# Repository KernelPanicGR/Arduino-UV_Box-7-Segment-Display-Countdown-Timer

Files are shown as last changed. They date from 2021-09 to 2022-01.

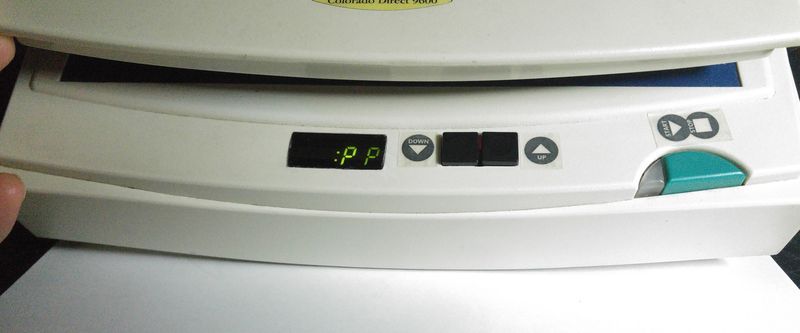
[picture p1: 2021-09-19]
Photos/Arduino_Countdown_Timer_7seg09.jpg

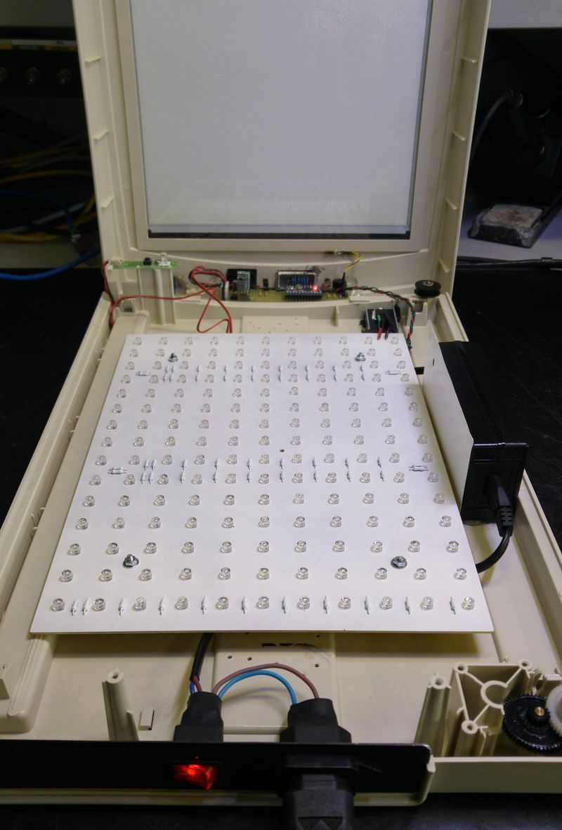
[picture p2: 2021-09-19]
Photos/Arduino_Countdown_Timer_7seg05.jpg

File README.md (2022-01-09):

# Arduino UV Box Countdown Timer 
Multiplexing 4-Digit 7-Segment Display<br/>
Easy change between Common Cathode or Common Anode Displays<br/>
Stores values into the EEPROM <br/>
max. countdown time 99:59 [min:sec]<br/>
Video https://vimeo.com/608781008<br/>

To change the countdown time, press the UP & DOWN buttons together.<br/>
With the UP or DOWN buttons put the time you want in minutes and press START/STOP which now works as SET. <br/>
Now change the seconds and press START/STOP again.<br/>
If other knowledge, repeat the previous steps, if you are ready press START/STOP to start the countdown.<br/>
If the time was different from the previous one Arduino had in EEPROM, the word Set will appear on the screen first,<br/>
the new time in EEPROM will be saved and then the reverse will start.

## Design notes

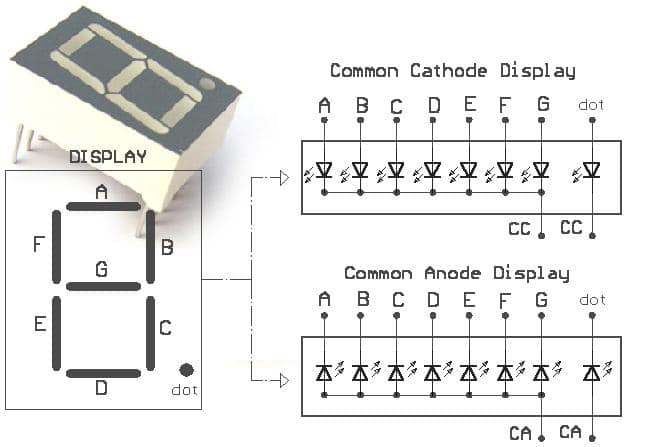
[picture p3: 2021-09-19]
Schematics/Diagram_7-Segment_Display.jpg

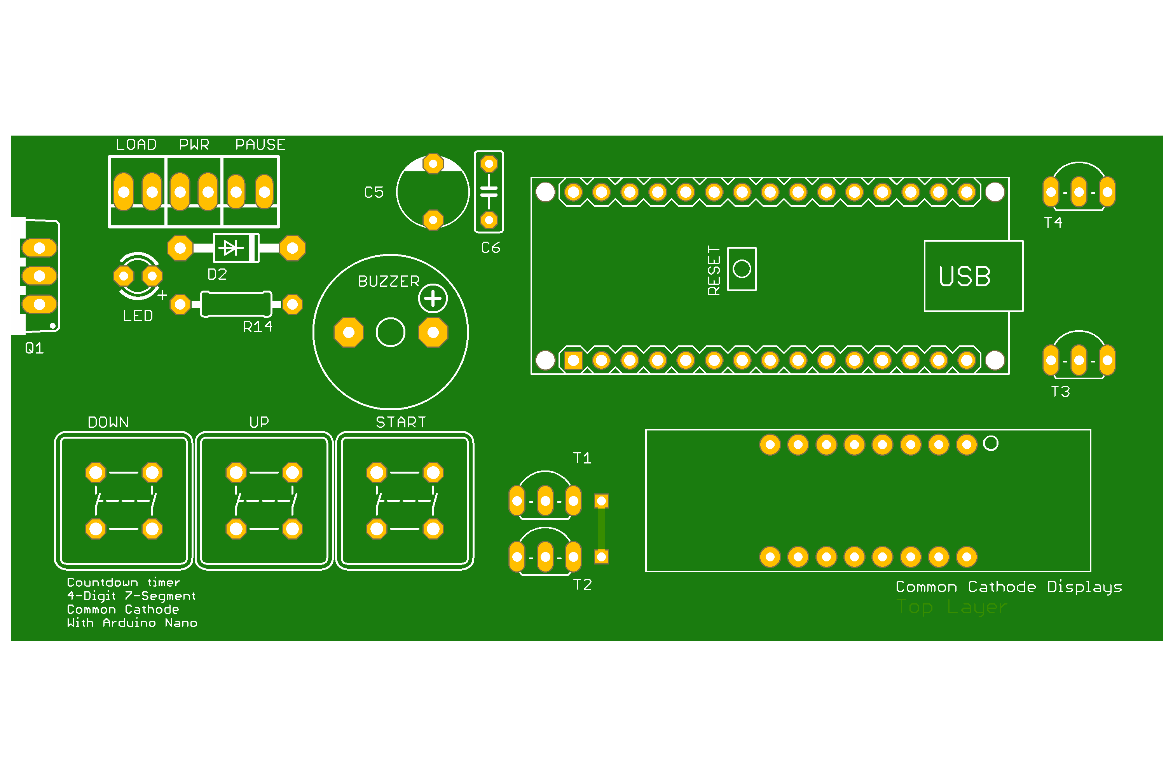
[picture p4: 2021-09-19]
Schematics/Arduino_Nano_Countdown_Timer_7-seg_CC_Top.png

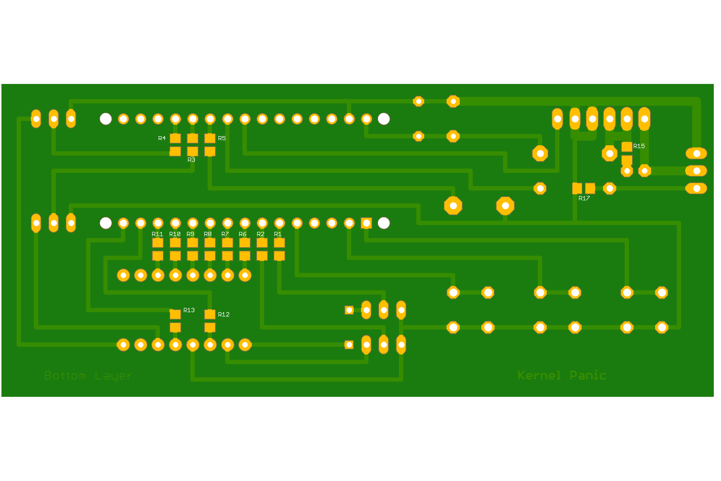
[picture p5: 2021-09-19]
Schematics/Arduino_Nano_Countdown_Timer_7-seg_CC_Bottom.png

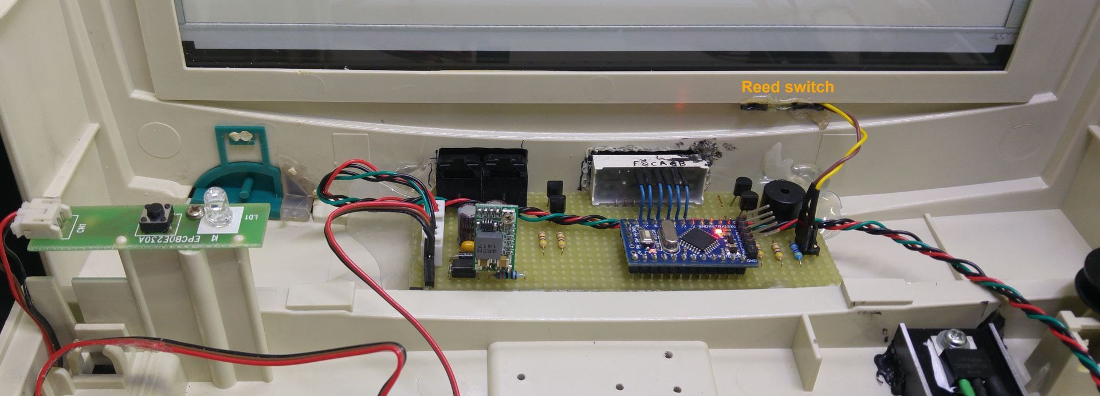
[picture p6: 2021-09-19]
Photos/Arduino_Countdown_Timer_7seg03.jpg

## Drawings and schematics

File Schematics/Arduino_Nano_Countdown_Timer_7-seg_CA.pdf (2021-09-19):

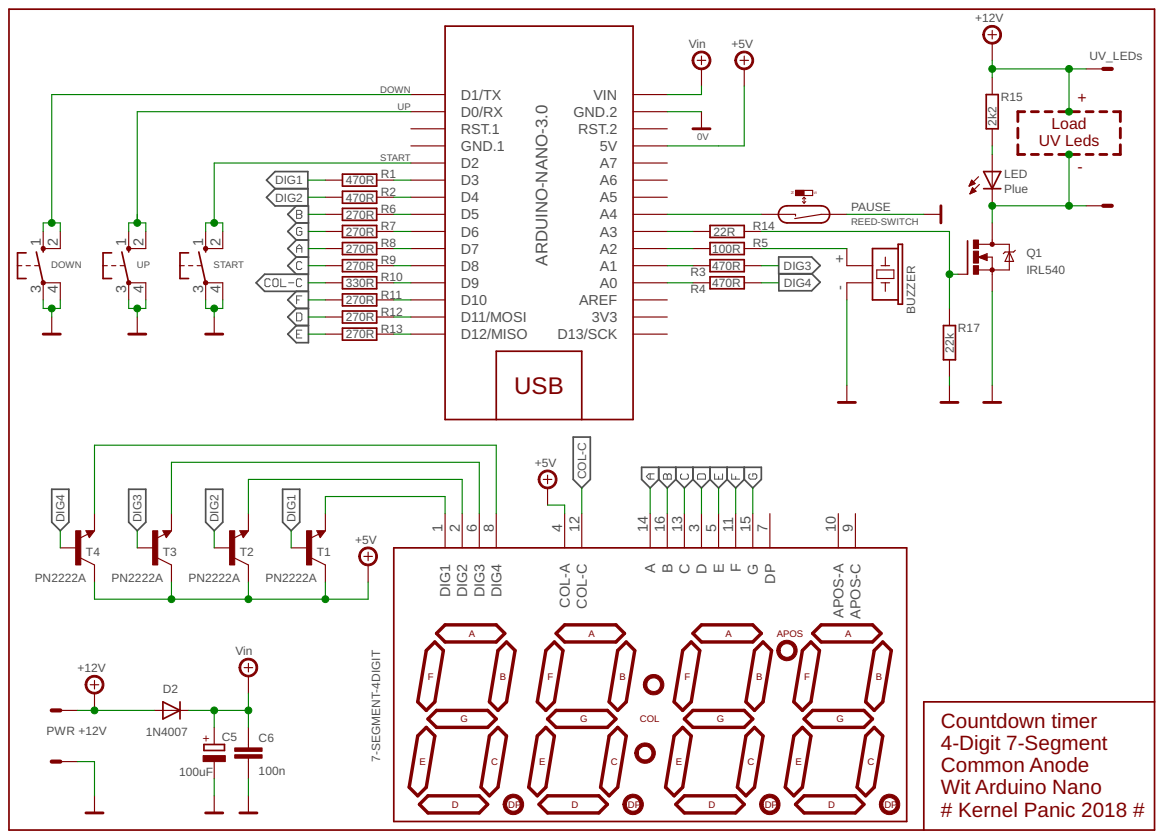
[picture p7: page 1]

DOWN
D1/TX D0/RX RST.1 GND.1 D2 D3 D4 D5 D6 D7 D8 D9 D10 D11/MOSI D12/MISO

270R | 470R
330R | 470R

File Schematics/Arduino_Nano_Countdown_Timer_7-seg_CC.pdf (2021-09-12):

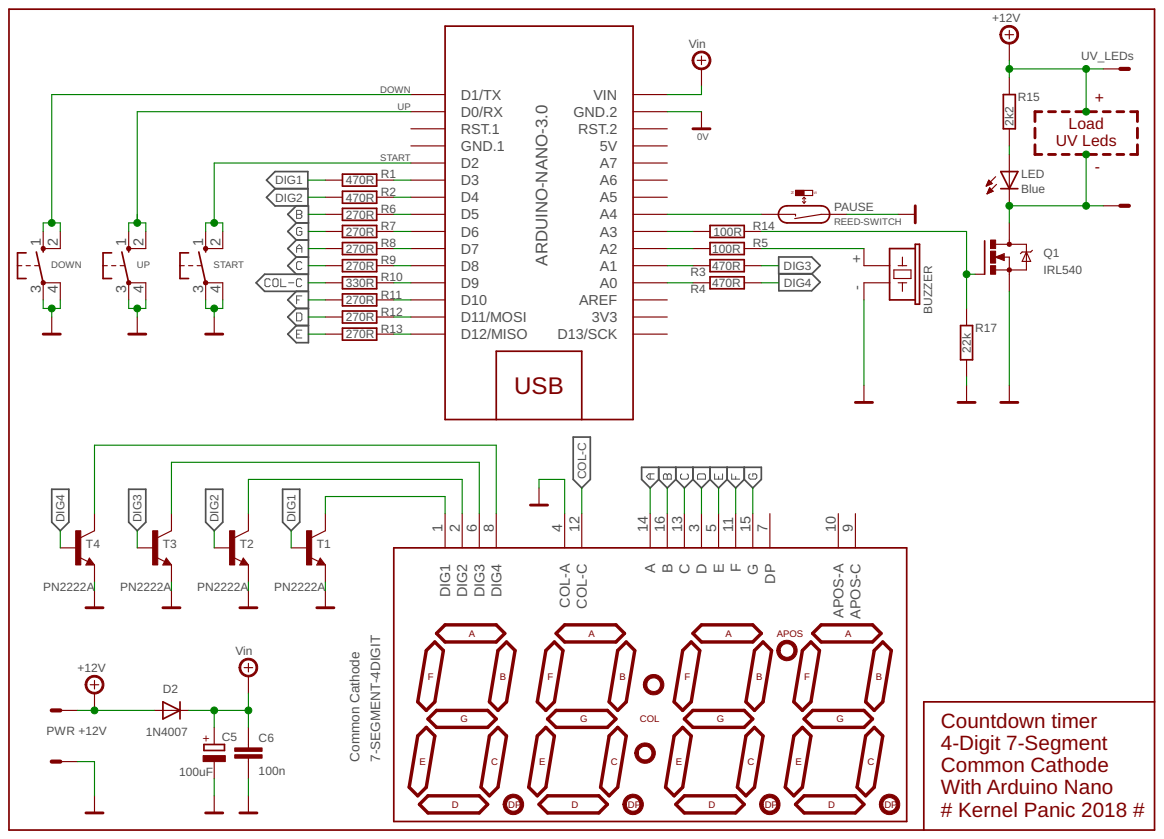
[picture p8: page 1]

DOWN
D1/TX D0/RX RST.1 GND.1 D2 D3 D4 D5 D6 D7 D8 D9 D10 D11/MOSI D12/MISO

270R | 470R
330R | 470R

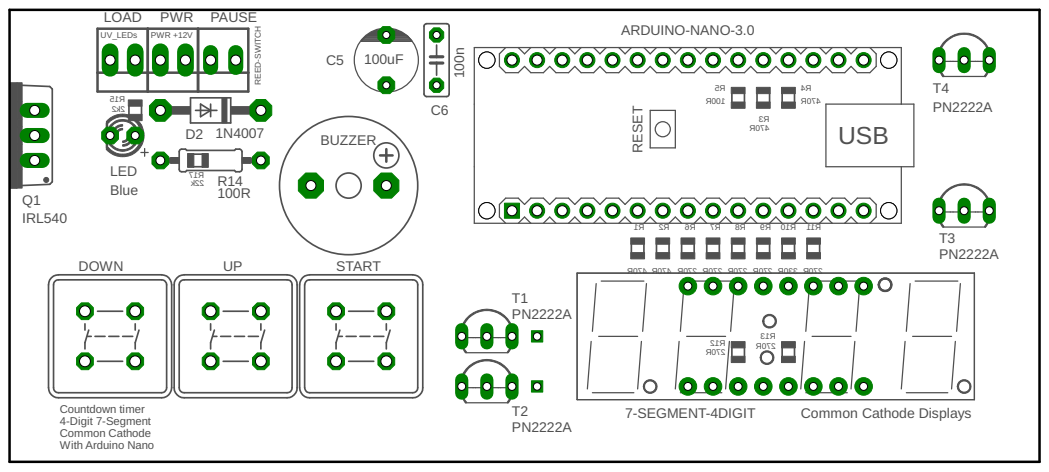
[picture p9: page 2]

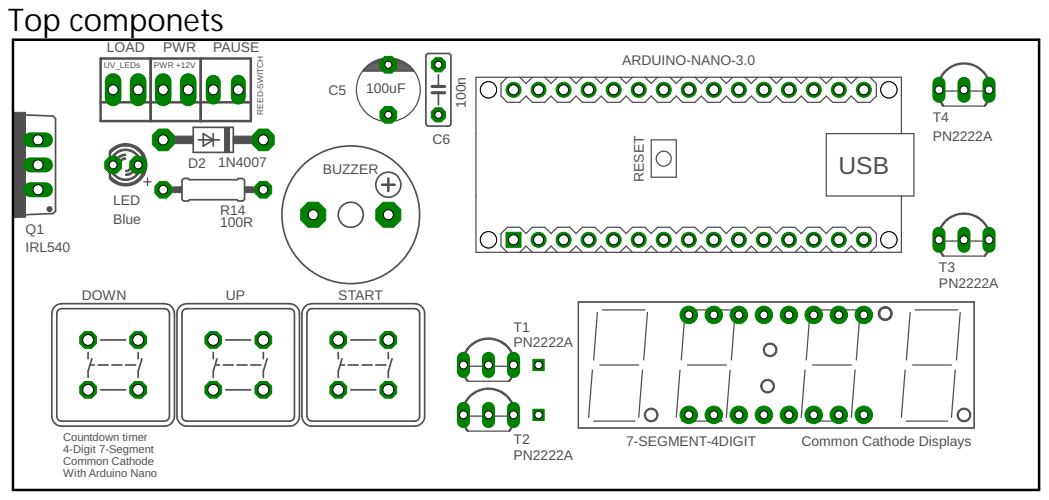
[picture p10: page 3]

Countdown timer 4-Digit 7-Segment Common Cathode With Arduino Nano

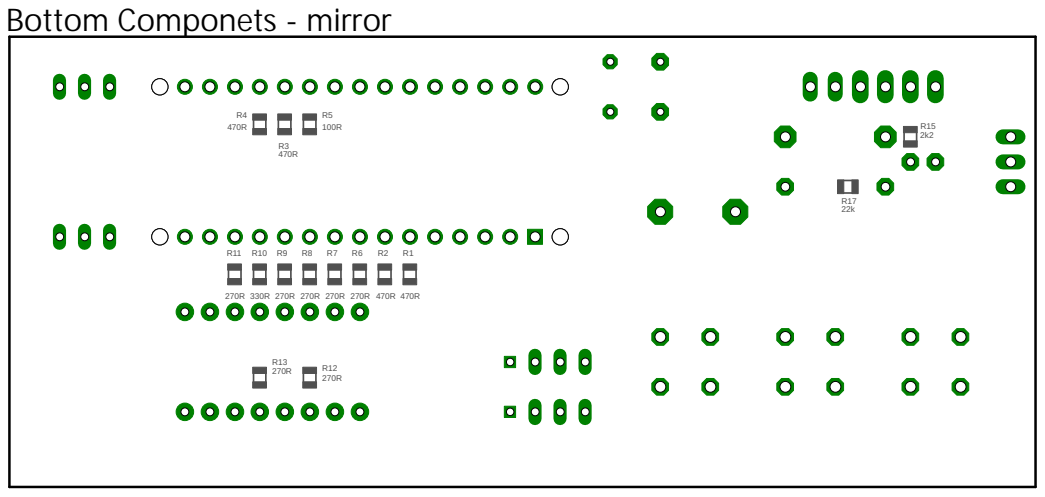
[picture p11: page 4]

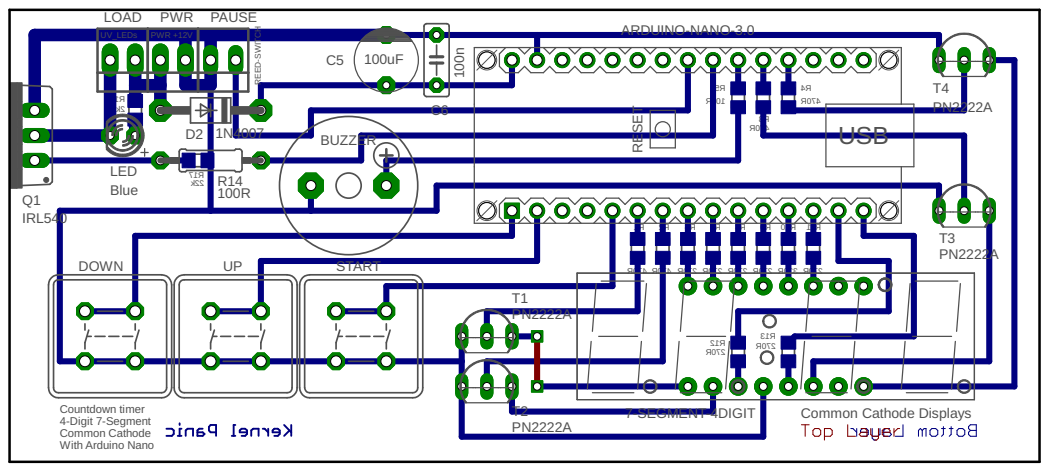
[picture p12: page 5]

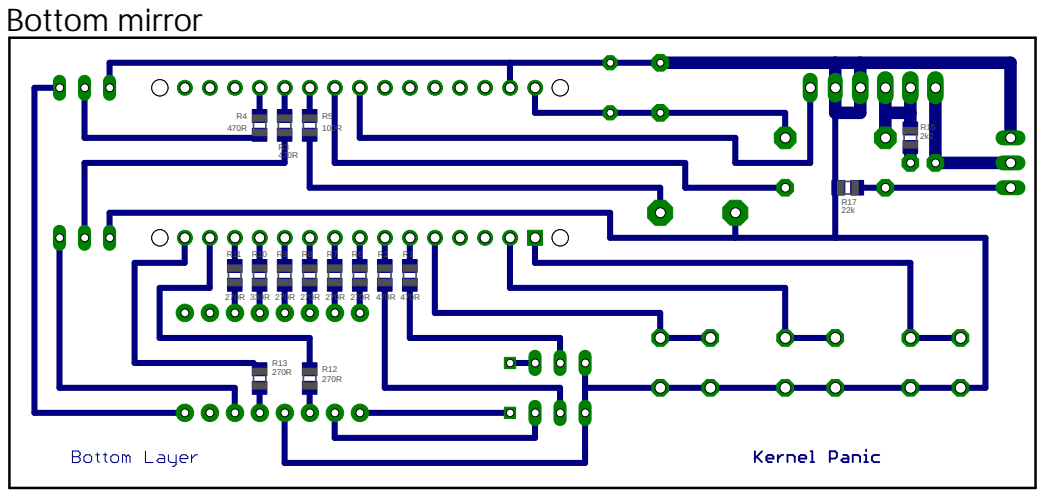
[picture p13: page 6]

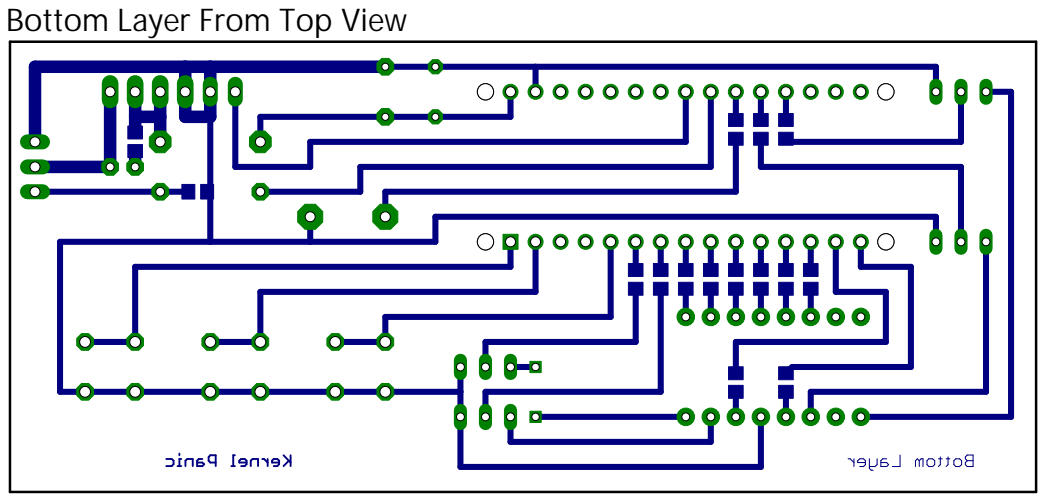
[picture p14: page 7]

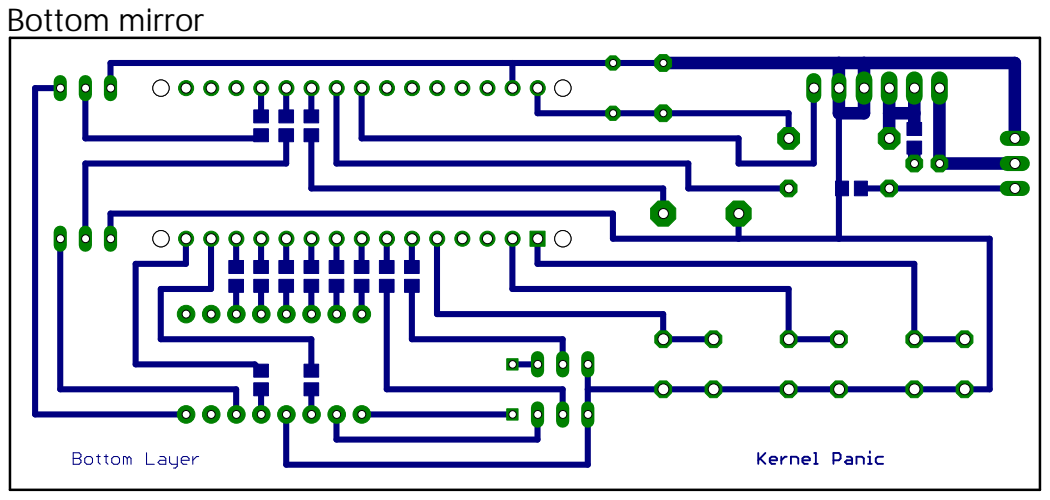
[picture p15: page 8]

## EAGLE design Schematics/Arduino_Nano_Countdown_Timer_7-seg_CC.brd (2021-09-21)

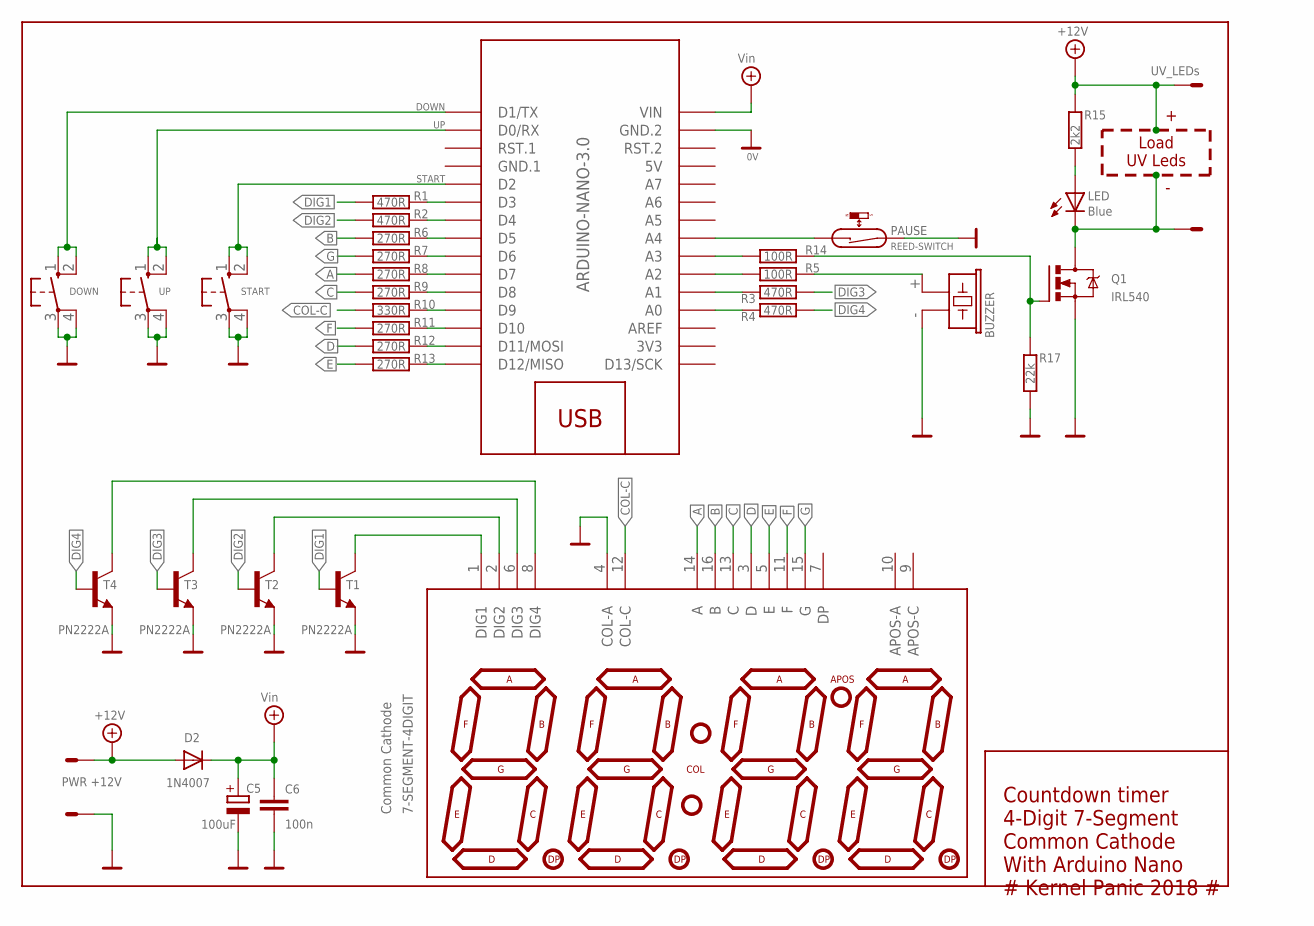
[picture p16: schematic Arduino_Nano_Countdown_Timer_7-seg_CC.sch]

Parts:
BUZZER: F/CM12P
C5: 100uF; E5-6.5
C6: 100n; C050-025X075
D2: 1N4007; DO41-10
DOWN: SWITCHE6K; DTE6K
LED: Blue; LED3MM
LED2: 7-SEGMENT-4DIGIT
LOAD: UV_LEDs; 22-23-2021
M2: ARDUINO-NANO-3.0
PAUSE: REED-SWITCH; 2PIN_HEADER
PWR: PWR +12V; 22-23-2021
Q1: IRL540; TO220BV
R1, R2, R3, R4: 470R; R0805
R5: 100R; R0805
R6, R7, R8, R9, R11, R12, R13: 270R; R0805
R10: 330R; R0805
R14: 100R; 0207/10-8
R15: 2k2; R0805
R17: 22k; R0805
START: SWITCHE6K; DTE6K
T1, T2, T3, T4: PN2222A; TO92-EBC-OVAL
UP: SWITCHE6K; DTE6K

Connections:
3V3: M2.J2.14 (3V3)
5V: M2.J2.4 (5V)
+12V: D2.A, LOAD.1, PWR.2, R15.1
A: LED2.14 (A), R8.1
B: LED2.16 (B), R6.1
BUZZER: BUZZER.+ (1), R5.1
C: LED2.13 (C), R9.1
COL-C: LED2.12 (COL-C), R10.1
D: LED2.3 (D), R12.1
DG1: LED2.1 (DIG1), T1.C
DG2: LED2.2 (DIG2), T2.C
DG3: LED2.6 (DIG3), T3.C
DG4: LED2.8 (DIG4), T4.C
DIG1: R1.1, T1.B
DIG2: R2.1, T2.B
DIG3: R3.1, T3.B
DIG4: R4.1, T4.B
DOWN: DOWN.1 (S), DOWN.2 (S), M2.J1.1 (D1/TX)
DP: M2.J1.12 (D9), R10.2
DRAIN: LED.K (C), LOAD.2, Q1.D
E: LED2.5 (E), R13.1
F: LED2.11 (F), R11.1
G: LED2.15 (G), R7.1
GATE: Q1.G, R14.2, R17.1
GND: BUZZER.- (2), C5.-, C6.2, DOWN.3, DOWN.4, LED2.4 (COL-A), M2.J2.2 (GND.2), PAUSE.2, PWR.1, Q1.S, R17.2, START.3, START.4, T1.E, T2.E, T3.E, T4.E, UP.3, UP.4
GND.1: M2.J1.4 (GND.1)
LED: LED.A, R15.2
unnamed: M2.J1.15 (D12/MISO), R13.2
unnamed: M2.J1.14 (D11/MOSI), R12.2
unnamed: M2.J2.10 (A2), R5.2
unnamed: M2.J2.9 (A3), R14.1
unnamed: M2.J1.13 (D10), R11.2
unnamed: M2.J1.6 (D3), R1.2
unnamed: M2.J2.11 (A1), R3.2
unnamed: M2.J1.7 (D4), R2.2
unnamed: M2.J2.8 (A4), PAUSE.1
unnamed: M2.J2.12 (A0), R4.2
unnamed: M2.J1.11 (D8), R9.2
unnamed: M2.J1.10 (D7), R8.2
unnamed: M2.J1.9 (D6), R7.2
unnamed: M2.J1.8 (D5), R6.2
START: M2.J1.5 (D2), START.1 (S), START.2 (S)
UP: M2.J1.2 (D0/RX), UP.1 (S), UP.2 (S)
VIN: C5.+, C6.1, D2.C, M2.J2.1 (VIN)

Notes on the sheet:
Load UV Leds
Countdown timer 4-Digit 7-Segment Common Cathode With Arduino Nano # Kernel Panic 2018 #
Common Cathode

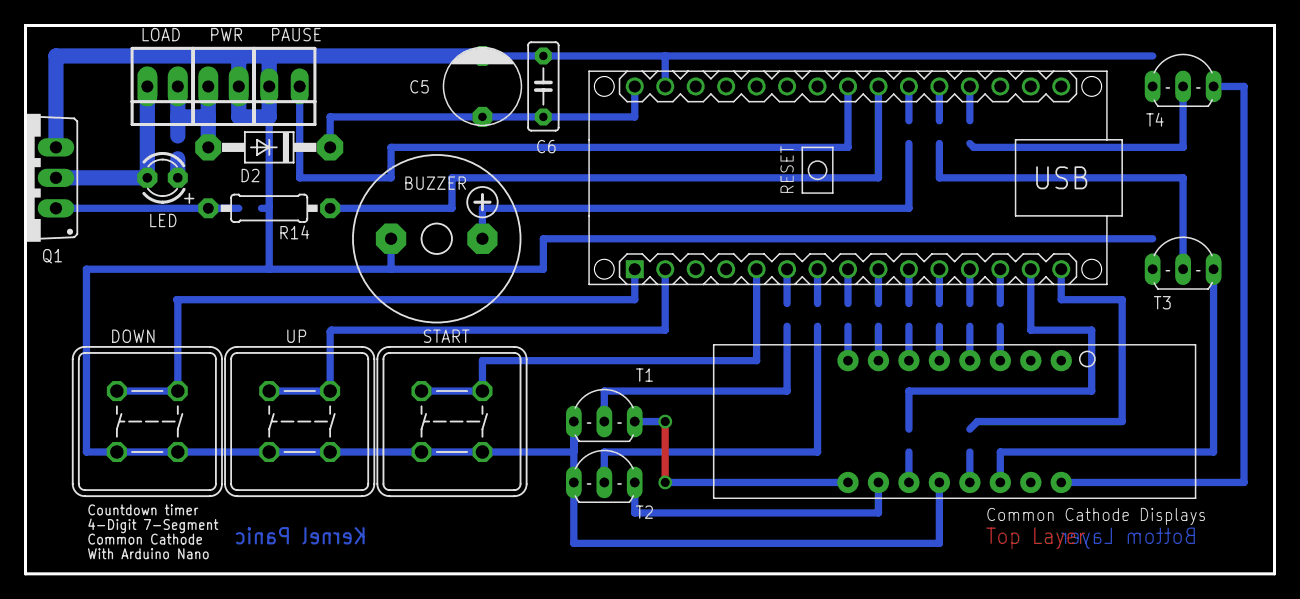
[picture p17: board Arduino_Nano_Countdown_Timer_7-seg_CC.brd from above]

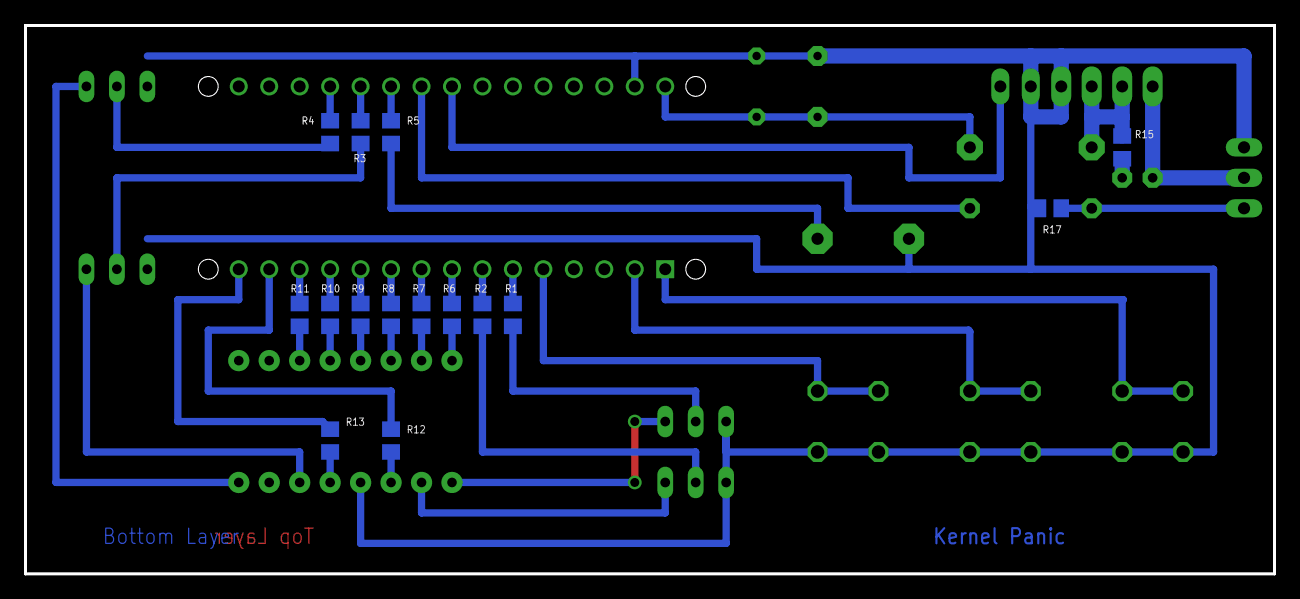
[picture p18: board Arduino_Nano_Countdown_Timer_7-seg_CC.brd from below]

Board: 2 copper layers, 104.1 x 45.7 mm, 34 parts (15 on the bottom side), 41 nets.

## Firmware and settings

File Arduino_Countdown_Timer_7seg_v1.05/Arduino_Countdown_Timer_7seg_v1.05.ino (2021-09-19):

/*
  Arduino Multiplexing 4-Digit 7-Segment Display Countdown Timer
  Easy change between Common Cathode and Common Anode Displays
  Stores values into the EEPROM
  max. countdown time 99:59 [min:sec]
  
  https://github.com/KernelPanicGR/Arduino-UV_Box-7-Segment-Display-Countdown-Timer
  
  https://vimeo.com/608781008
  
  To change the countdown time, press the UP & DOWN buttons together. 
  With the UP or DOWN buttons put the time you want in minutes and press START/STOP which now works as SET.
  Now change the seconds and press START/STOP again.
  If other knowledge, repeat the previous steps, if you are ready press START/STOP to start the countdown.
  If the time was different from the previous one Arduino had in EEPROM, 
  the word Set will appear on the screen first, the new time in EEPROM will be saved and then the reverse will start.
   _________________________________
  | Arduino: IDE 1.8.15             |
  | Board  : Arduino Nano           |
  | Project: UV_Box_Timer_7seg      |
  | Version: 1.05                   |
  | First version: 11/11/2017       |
  | Last update  : 17/09/2021       |
  | Author       : kernel panic     |
  |_________________________________|
   _________________________________
  |   7-Segment Display map         |
  |        AAA                      |
  |       F   B                     |
  |       F   B                     |
  |        GGG                      |
  |       E   C                     |
  |       E   C                     |
  |        DDD                      |
  |_________________________________|
*/

//============================================================
#include <EEPROM.h>

//============================================================
#define PIN_UP      0   // Button UP Countdown
#define PIN_DOWN    1   // Button Down Countdown
#define PIN_START   2   // Button Start or STOP
#define PIN_PAUSE   A4  // Reed switch for Pause
#define POWER_OUT   A3  // output pin For on off 
#define BUZZER      A2  // output BUZZER pin
//     arduino pins for segments
#define A       7
#define B       5
#define C       8
#define D       11
#define E       12
#define F       10
#define G       6
#define DP      9
//     arduino pins for digits
#define DIG_1   3
#define DIG_2   4
#define DIG_3   A1
#define DIG_4   A0

#define BEEP_SEC        6   // Beep for the last seconds
#define DB_MS           30  // Buttons Debounce time in milliseconds
#define EEPROM_MINUTE   0   // address of the EEPROM
#define EEPROM_SEC      1   // address of the EEPROM
#define SPEED_COUNTER   350 // milliseconds

#define ON  HIGH
#define OFF LOW
#define YES true
#define NO  false

// set clock -> start = 0x04,  stop = 0x00
#define START_TIMER TCCR1B = 0x04;
#define STOP_TIMER  TCCR1B = 0x00;
//============================================================

bool My_Display_is_CA = NO, // Change type Displays, YES=CA,  NO=CC

     FlagBeep = false,
     FlagEnd  = false,
     FlagSetSec = false,
     FlagSetMin = false,
     FlagStartCountdown = false,
     FlagSetUpDownTime = false;

// create an array of pins for BUTTONS
const uint8_t BUTTONS[] = {PIN_UP, PIN_DOWN, PIN_START, PIN_PAUSE};
const size_t  NBR_BTNS  = sizeof(BUTTONS);

uint16_t count, Speed; // for buttons  actions

//int8_t Minutes, Seconds;
int     Seconds;
uint8_t Minutes;

/*
  7 segments leds
  bits representing segments A through G and decimal point
  for numerals 0-9 and some characters
*/
const uint8_t SEGMENTS[21] = {
  //ABCDEFGdp segments
  B11111100, // 0 /  0
  B01100000, // 1 /  1
  B11011010, // 2 /  2
  B11110010, // 3 /  3
  B01100110, // 4 /  4
  B10110110, // 5 /  5
  B00111110, // 6 /  6
  B11100000, // 7 /  7
  B11111110, // 8 /  8
  B11100110, // 9 /  9
  B10110110, // S / 10
  B10011110, // E / 11
  B00011110, // t / 12
  B01101110, // H / 13
  B00001000, // i / 14
  B11001110, // P / 15
  B00000010, // - / 16
  B00000000, //   / 17 - shows nothing
  B00101010, // n / 18
  B01111010, // d / 19
  B00111010, // o / 20
};

const uint8_t SEGMENT[] = {DP, G, F, E, D, C, B, A};
const uint8_t NBR_DIGITS = 4; // the number of digits in the LED display
const uint8_t DIGIT[NBR_DIGITS] = {DIG_1, DIG_2, DIG_3, DIG_4};


/* ======================================================================
  Timer interrupt
  https://www.electronicsblog.net/examples-of-using-arduinoatmega-16-bit-hardware-timer-for-digital-clock/
  ======================================================================= */
ISR(TIMER1_OVF_vect) {
  Seconds --;

  if (Minutes == 0 && Seconds < BEEP_SEC) {
    FlagBeep = true;
  }

  digitalWrite(DP, !digitalRead(DP));
  TCNT1 = 0x0BDC ; // 0x0BDC set initial value to remove time error (16bit counter register)
}

//========================================================
// setup function
//========================================================
void setup() {
  /* make buttons pins as input */
  for (uint8_t btn = 0; btn < NBR_BTNS; btn++) {
    pinMode(BUTTONS[btn], INPUT_PULLUP);
  }

  /* setup pins as output */
  for (uint8_t s = 0; s < 8; s++)   {
    pinMode(SEGMENT[s], OUTPUT); //
    digitalWrite(SEGMENT[s], OFF);
  }

  for (uint8_t d = 0; d < NBR_DIGITS; d++) {
    pinMode(DIGIT[d], OUTPUT);
    digitalWrite(DIGIT[d], OFF);
  }

  pinMode(LED_BUILTIN, OUTPUT);
  pinMode(BUZZER, OUTPUT);
  pinMode(POWER_OUT, OUTPUT);

  digitalWrite(BUZZER, OFF);
  digitalWrite(POWER_OUT, OFF);
  digitalWrite(LED_BUILTIN, OFF);

  // Display Hi
  for (uint8_t i = 0; i < 60; i++) {
    showDigit(13, 1); // H
    showDigit(14, 2); // i
  }

  // timer
  TIMSK1 = 0x01;    // enabled global and timer overflow interrupt;
  TCCR1A = 0x00;    // normal operation (mode0);
  TCNT1  = 0x0BDC;   // 0x0BDC set initial value to remove time error (16bit counter register)
  STOP_TIMER;

  // EEPROM
  Minutes = EEPROM.read(EEPROM_MINUTE);  // read minute from address of the EEPROM
  Seconds = EEPROM.read(EEPROM_SEC);     // read seconds from address of the EEPROM

  if (Minutes > 99 || Seconds > 59)
    Minutes = 1, Seconds = 23;

  digitalWrite(DP, ON);
  StartMelody();
}//== Close setup =====

//========================================================
// loop
//========================================================
void loop() {
  if (!FlagSetUpDownTime && WasPressed(PIN_START))  {

    if (WasReleased(PIN_PAUSE)) {   // Pause
      Pause();
    } else {                        // Start Countdown
      FlagStartCountdown = true;
      StartCountdown();
    }

    if (FlagEnd)                    // End Countdown
      CountdownEND();
  }

  UpDownCounter();
  UpdateDisplay();

}//== Close loop =====

//========================================================
// StartCountdown
//========================================================
void StartCountdown() {
  //--- Store EEPROM only if different ---
  FlagBeep = false;
  if (EEPROM.read(EEPROM_MINUTE) != Minutes || EEPROM.read(EEPROM_SEC) != Seconds) {
    digitalWrite(DP, OFF);
    EEPROM.update(EEPROM_MINUTE, Minutes);
    EEPROM.update(EEPROM_SEC, Seconds);
    //-- Display SEt --
    for (uint8_t i = 0; i < 60; i++)   {
      showDigit (10, 0); // S
      showDigit (11, 1); // E
      showDigit (12, 2); // t
    }
  } //--Close Store EEPROM -----

  PlayStart();
  START_TIMER;
  digitalWrite(POWER_OUT, ON);

  //--- Countdown Loop ----
  while (FlagStartCountdown) {
    if (Minutes == 0 && Seconds == 0) {
      FlagEnd = true ;
      FlagStartCountdown = false ;
    }

    if (FlagBeep) {
      Beep(1760, 24);
      FlagBeep = false;
    }

    if (Seconds < 0) {
      Minutes --;
      Seconds = 59;
    }

    //--- Pause ----
    if (WasReleased(PIN_PAUSE)) {
      Pause();
      START_TIMER;
      digitalWrite(POWER_OUT, ON);
    }

    //-- STOP ----
    if (WasPressed(PIN_START)) {
      digitalWrite(POWER_OUT, OFF);
      STOP_TIMER;
      digitalWrite(DP, OFF);
      for (uint8_t i = 0; i < 80; i++) {
        showDigit (10, 0); // S
        showDigit (12, 1); // t
        showDigit (20, 2); // 0
        showDigit (15, 3); // P
      }
      FlagEnd = true ;
      FlagStartCountdown = false ;
    }

    UpdateDisplay();
  }//--Close while Countdown Loop ----

}// == Close StartCountdown() ===

//========================================================
// CountdownEND
//========================================================
void CountdownEND() {
  digitalWrite(POWER_OUT, OFF);
  STOP_TIMER;
  digitalWrite(DP, OFF);
  EndMelody();

  do {
    showDigit(11, 0); // E
    showDigit(18, 1); // n
    showDigit(19, 2); // d

    if (WasPressed(PIN_START)) {
      Minutes = EEPROM.read(EEPROM_MINUTE);
      Seconds = EEPROM.read(EEPROM_SEC);
      FlagEnd = false ;
    }
  }
  while (FlagEnd) ; // End
  digitalWrite(DP, ON);
}

//========================================================
// Set Up and Down Counter Time
//========================================================
void UpDownCounter() {
  // buttons state
  static bool BTN_UP = true,
              BTN_DOWN = true,
              oldBTN_UP = false,
              oldBTN_DOWN = false,
              BTN_Press = false;

  static uint32_t BtnTime; // buttons press time

  // Read the buttons
  BTN_UP   = digitalRead(PIN_UP);
  BTN_DOWN = digitalRead(PIN_DOWN);

  // if state changed since last read
  if (BTN_UP != oldBTN_UP | BTN_DOWN != oldBTN_DOWN) {
    oldBTN_UP   = BTN_UP;
    oldBTN_DOWN = BTN_DOWN;

    if (BTN_UP && BTN_DOWN) {
      BtnTime = millis();
      count = 0 ;
      Speed = SPEED_COUNTER;
      BTN_Press = false;
    }
  }

  if (!BTN_Press && !BTN_UP && !BTN_DOWN && millis() - BtnTime > SPEED_COUNTER) {
    FlagSetUpDownTime = true;
    FlagSetMin = true;
    FlagSetSec = false;
    BTN_Press  = true;
    Beep(1976, 32);
    Beep(1, 24);
    Beep(3951, 20);
    BtnTime = millis();
  }

  if (FlagSetUpDownTime && !BTN_Press) {
    if (WasPressed(PIN_START)) {
      if (FlagSetMin ) {
        FlagSetMin = false;
        FlagSetSec = true;
      }
      else {
        FlagSetMin = false;
        FlagSetSec = false;
        FlagSetUpDownTime = false;
        digitalWrite(LED_BUILTIN, OFF);
      }
      Beep(880, 20);
      Beep(1, 24);
      Beep(1760, 32);
    }

    // change Minutes
    if (FlagSetMin) {
      if (!BTN_UP && millis() - BtnTime > Speed) {
        Minutes ++ ;
        Minutes %= 100; //  After 99 Reset Minutes to 0
        ProcessSpeed();
        BtnTime = millis();
      }

      if (!BTN_DOWN && millis() - BtnTime > Speed) {
        if (Minutes > 99) Minutes = 0;
        else if (Minutes == 0) Minutes = 99;
        else Minutes --;

        ProcessSpeed();
        BtnTime = millis();
      }
    }

    // change Seconds
    if (FlagSetSec) {
      if (!BTN_UP && millis() - BtnTime > Speed) {
        Seconds ++ ;
        Seconds %= 60; // Reset Seconds after 59
        ProcessSpeed();
        BtnTime = millis();
      }

      if (!BTN_DOWN && millis() - BtnTime > Speed) {
        if (Seconds > 59) Seconds = 0;
        else if (Seconds == 0) Seconds = 59;
        else Seconds --;

        ProcessSpeed();
        BtnTime = millis();
      }
    }
  }

  // Blink led
  if (FlagSetUpDownTime)
    digitalWrite(LED_BUILTIN, (millis() / 250) % 2 ? HIGH : LOW);

}//== Close UpDownCounter() ===

//========================================================
// ProcessSpeed
//========================================================
void ProcessSpeed() {
  count++;
  if        (count > 30) Speed = 40;
  else if   (count > 20) Speed = 70;
  else if   (count > 9 ) Speed = 150; //
} //== Close ProcessSpeed() ===


//========================================================
// Pause
//========================================================
void Pause() {
  STOP_TIMER;
  digitalWrite(POWER_OUT, OFF);
  digitalWrite(DP, OFF);

  //-- Animation P --
  while (isReleased(PIN_PAUSE)) { //-- while --
    for (int8_t digit = NBR_DIGITS - 1; digit >= 0; digit--) {
      for (uint8_t i = 0; i < 50; i++) {
        showDigit (15, digit); // P
      }
    }
    for (uint8_t Dig = 1; Dig <= 2; Dig++) {
      for (uint8_t i = 0; i < 50; i++) {
        showDigit (15, Dig); // P
      }
    }
    Beep(3520, 36);
  }//--Close while Animation P ---
}//== Close Pause() =====

//======================================================================
// UpdateDisplay
//======================================================================
void UpdateDisplay() {  // mmss
  if (!FlagSetSec) {
    showDigit (Minutes / 10, 0);
    showDigit (Minutes % 10, 1);
  }
  if (!FlagSetMin) {
    showDigit (Seconds / 10, 2);
    showDigit (Seconds % 10, 3);
  }
}//==Close UpdateDisplay ====

//======================================================================
// showDigit
//======================================================================
// Displays given number on a 7-segment display at the given digit position
void showDigit(uint8_t number, uint8_t dig) {
  digitalWrite(DIGIT[dig], HIGH );

  for (uint8_t seg = 1; seg < 8; seg++) {
    // isBitSet will be true if given bit is 1
    bool isBitSet = bitRead(SEGMENTS[number], seg);

    // for Common Anode Display
    if (My_Display_is_CA)
      isBitSet = !isBitSet;

    digitalWrite(SEGMENT[seg], isBitSet);
  }

  delay(5); // delay before disabling the current digit so the human eye can observe it

  digitalWrite(DIGIT[dig], LOW);
}//==Close showDigit ====

/* ======================================================================
  Melody
  url: http://www.arduino.cc/en/Tutorial/Tone
  ======================================================================= */
//uint16_t EndMelody_note[]		= { 262, 196, 196, 220, 196, 0, 247, 262 }; // original
//uint16_t EndMelody_note[]		= {1047, 784, 784, 880, 784, 0, 988, 1047};
uint16_t EndMelody_note[]		= {4186, 3136, 3136, 3520, 3136, 0, 3951, 4186};

uint16_t EndMelody_durations[]	= {4, 8, 8, 4, 4, 4, 4, 4};

void EndMelody() {
  //iterate over the notes of the melody
  for (uint16_t thisNote = 0; thisNote < 8; thisNote++) {
    //to calculate the note duration, take one second. Divided by the note type
    uint16_t noteDuration = 1000 / EndMelody_durations[thisNote];
    tone(BUZZER, EndMelody_note [thisNote], noteDuration);

    //to distinguish the notes, set a minimum time between them
    uint16_t pauseBetweenNotes = noteDuration * 1.30;
    delay(pauseBetweenNotes);

    //stop the tone playing
    noTone(BUZZER);
  }
}//==Close EndMelody ====

//=======================================================
// StartMelody
//=======================================================
uint16_t Start_note[]      = { 1175, 1047, 880, 1319, 1175 };
uint8_t Start_duration[]   = {10,  12, 10, 10, 4 };

void StartMelody() {
  for (uint16_t thisNote = 0; thisNote < (sizeof(Start_note) / sizeof(int)); thisNote++) {

    uint16_t noteDuration = 1000 / Start_duration[thisNote]; //convert duration to time delay
    tone(BUZZER, Start_note[thisNote], noteDuration);

    uint16_t pauseBetweenNotes = noteDuration * 1.30;//Here 1.30 is tempo, decrease to play it faster
    delay(pauseBetweenNotes);
    noTone(BUZZER); //stop music on pin
  }
}

//=======================================================
// PlayStart
//=======================================================
uint16_t PlayStart_note[]     = {2349, 2637 };
uint8_t  PlayStart_duration[] = {12,  8  };

void PlayStart() {
  for (uint16_t thisNote = 0; thisNote < (sizeof(PlayStart_note) / sizeof(int)); thisNote++) {

    uint16_t noteDuration = 1000 / PlayStart_duration[thisNote]; //convert duration to time delay
    tone(BUZZER, PlayStart_note[thisNote], noteDuration);

    uint16_t pauseBetweenNotes = noteDuration * 1.30;//Here 1.30 is tempo, decrease to play it faster
    delay(pauseBetweenNotes);
    noTone(BUZZER); //stop music on pin
  }
}

//=======================================================
// Beep
//=======================================================
void Beep(uint16_t freq, uint16_t duration) {
  uint16_t noteDuration = 1000 / duration; //convert duration to time delay
  tone(BUZZER, freq, noteDuration);

  uint16_t pauseBetweenNotes = noteDuration * 1.30;//Here 1.30 is tempo, decrease to play it faster
  delay(pauseBetweenNotes);

  noTone(BUZZER);
}

//=======================================================
// Buttons
//=======================================================
bool StableBtnLevel[20]; //
//=== CheckButton =======================================
bool CheckButton(uint8_t Btn_pin) {
  bool prvBtnLevel    = StableBtnLevel[Btn_pin];    // the previous steady state from the input pin
  bool newLevel       = getBtnStableLevel(Btn_pin);
  return prvBtnLevel != newLevel;
}//== Close CheckButton ==

bool getBtnStableLevel(uint8_t Btn_pin) {
  static bool OLDbtnLevels[20]; //
  static uint32_t BtnPressTime;
  // Reads a digital pin and filters it, returning the stable button position
  bool  pinLevel = digitalRead(Btn_pin);
  if (pinLevel != OLDbtnLevels[Btn_pin]) {
    BtnPressTime = millis();
    OLDbtnLevels[Btn_pin] = pinLevel;
  }
  // Debounce
  if (( millis() - BtnPressTime) > DB_MS) {
    StableBtnLevel[Btn_pin] = pinLevel;
  }
  return StableBtnLevel[Btn_pin];
}

// Read the state input pin
bool ReadThePin( uint8_t Pin ) {
  return digitalRead(Pin);
}

bool WasPressed( uint8_t Pin ) {
  return CheckButton(Pin) && !getBtnStableLevel(Pin);
}

bool WasReleased( uint8_t Pin ) {
  return CheckButton(Pin) && getBtnStableLevel(Pin);
}
// The button is pressed (with debounce)
bool isPressedDB( uint8_t Pin ) {
  return !getBtnStableLevel(Pin);
}
// The button is released (with debounce)
bool isReleasedDB( uint8_t Pin ) {
  return getBtnStableLevel(Pin);
}
// The button is pressed (without debounce)
bool isPressed( uint8_t Pin ) {
  return !ReadThePin(Pin);
}
// The button is released (without debounce)
bool isReleased( uint8_t Pin ) {
  return ReadThePin(Pin);
}
//== End Buttons ===


/*********( END Code )***********/

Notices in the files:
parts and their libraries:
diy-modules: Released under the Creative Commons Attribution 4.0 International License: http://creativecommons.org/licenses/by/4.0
